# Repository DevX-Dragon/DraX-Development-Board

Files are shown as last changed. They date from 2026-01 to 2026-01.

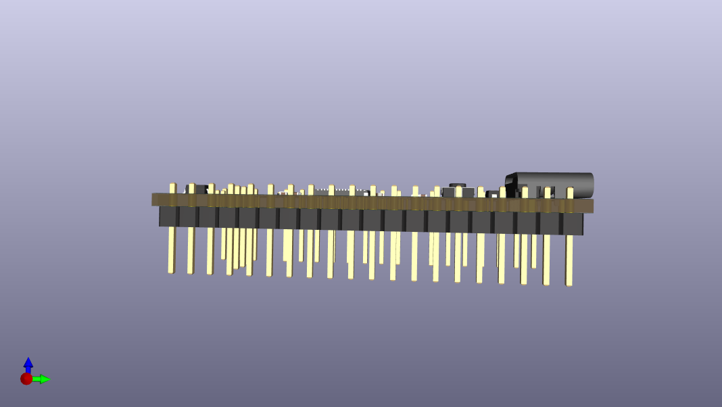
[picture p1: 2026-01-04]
Images/Board 3D side.png

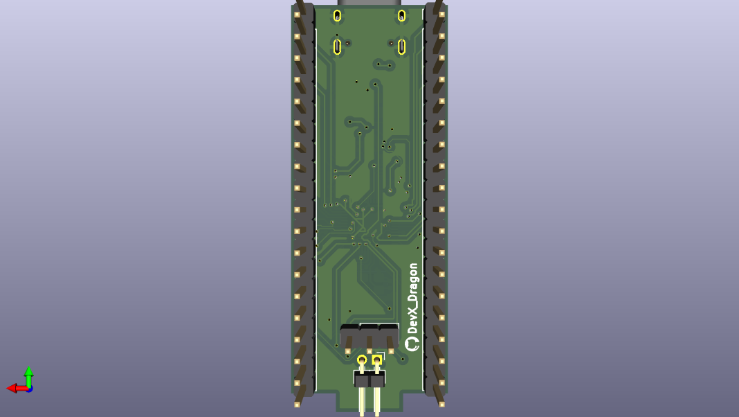
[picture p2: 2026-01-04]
Images/Board 3D back.png

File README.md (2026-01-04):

# DraX Development Board
A compact, high-performance development board based on the RP2040 microcontroller, designed for versatility with dual power options and easy breadboard integration.

## Layouts
PCB Layout

Schematics Layout

## Renders
front view
Front
back
side

## Technical Specifications

**Microcontroller:**
Raspberry Pi RP2040 dual-core ARM Cortex-M0+.

**Storage:** 
16MB (128Mbit) QSPI Flash memory (W25Q128).

**Power Input:** 
Dual-power path with Schottky diode protection (D1, D2).

**USB-C:**
5V via 14-pin USB-C receptacle.

**Battery:**
JST-style connector for LiPo battery support.

**Regulation:**
On-board LDO regulator (NCP1117) providing stable 3.3V.

**Clock:**
12MHz crystal oscillator with 15pF load capacitors.

**I/O:**
40-pin total breakout via dual 20-pin headers (J2, J3) including GPIO and ADC.

**Debugging:**
Dedicated SWD (Serial Wire Debug) header (J4).

**User Interface:**
Tactile Push-buttons for Reset and BOOTSEL modes.

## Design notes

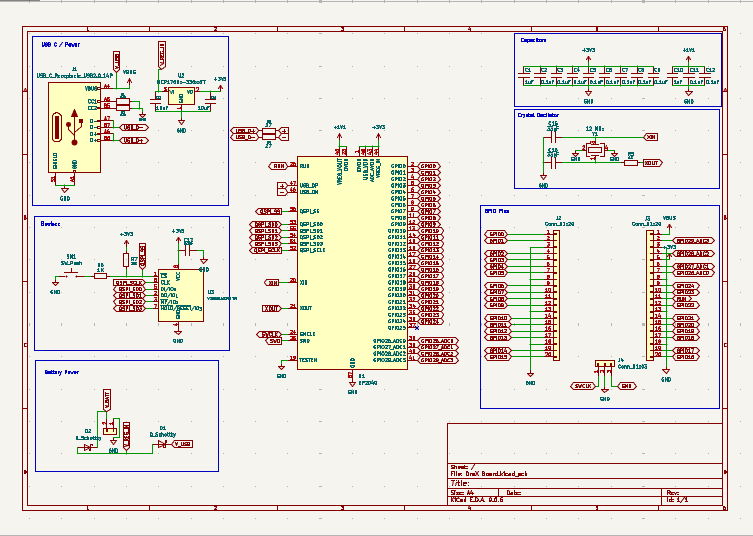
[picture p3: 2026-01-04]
Images/Schematics Layout.png

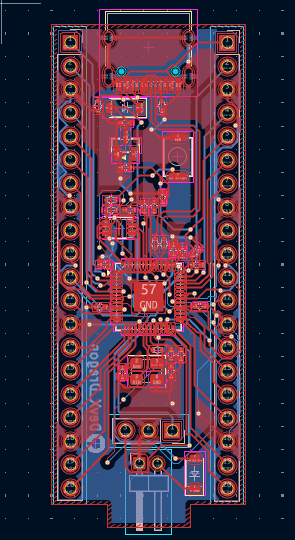
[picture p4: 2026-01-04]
Images/PCB Layout.png

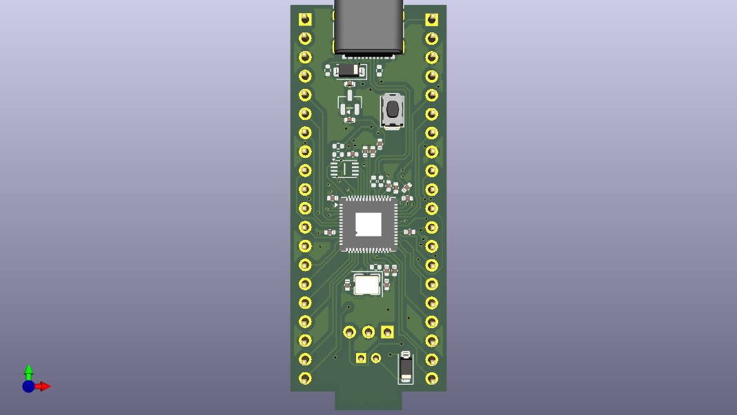
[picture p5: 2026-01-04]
Images/Board 3D front.png

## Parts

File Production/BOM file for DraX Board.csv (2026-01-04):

Designator | Footprint | Quantity | Comment | Supplier and ref
C13, C14 | C_0402_1005Metric | 2 | 10uF
R7, R6 | R_0402_1005Metric | 2 | 10K / 1K
C8, C4, C11, C7, C12, C5, C17, C9, C3, C2, C6 | C_0402_1005Metric | 11 | 0.1uF
R5 | R_0402_1005Metric | 1 | 1K
R1, R2 | R_0402_1005Metric | 2 | 5.1K
R4, R3 | R_0402_1005Metric | 2 | 27
C16, C15 | C_0402_1005Metric | 2 | 33pF
U3 | Winbond_USON-8-1EP_3x2mm_P0.5mm_EP0.2x1.6mm | 1 | W25Q16JVZPIQ TR
J1 | USB_C_Receptacle_HRO_TYPE-C-31-M-12 | 1 | USB_C_Receptacle_USB2.0_14P
C1, C10 | C_0402_1005Metric | 2 | 1uF
U1 | QFN-56-1EP_7x7mm_P0.4mm_EP3.2x3.2mm | 1 | RP2040
D1, D2 | D_SOD-123 | 2 | D_Schottky
Y1 | Crystal_SMD_3225-4Pin_3.2x2.5mm | 1 | 12 MHz
U2 | SOT-23 | 1 | MCP1700x-330xxTT
J3, J2 | PinHeader_1x20_P2.54mm_Vertical | 2 | Conn_01x20
J4 | PinHeader_1x03_P2.54mm_Vertical | 1 | Conn_01x03
J5 | PinHeader_1x02_P2.00mm_Horizontal | 1 | Conn_01x02
SW1 | SW_Push_SPST_NO_Alps_SKRK | 1 | SW_Push

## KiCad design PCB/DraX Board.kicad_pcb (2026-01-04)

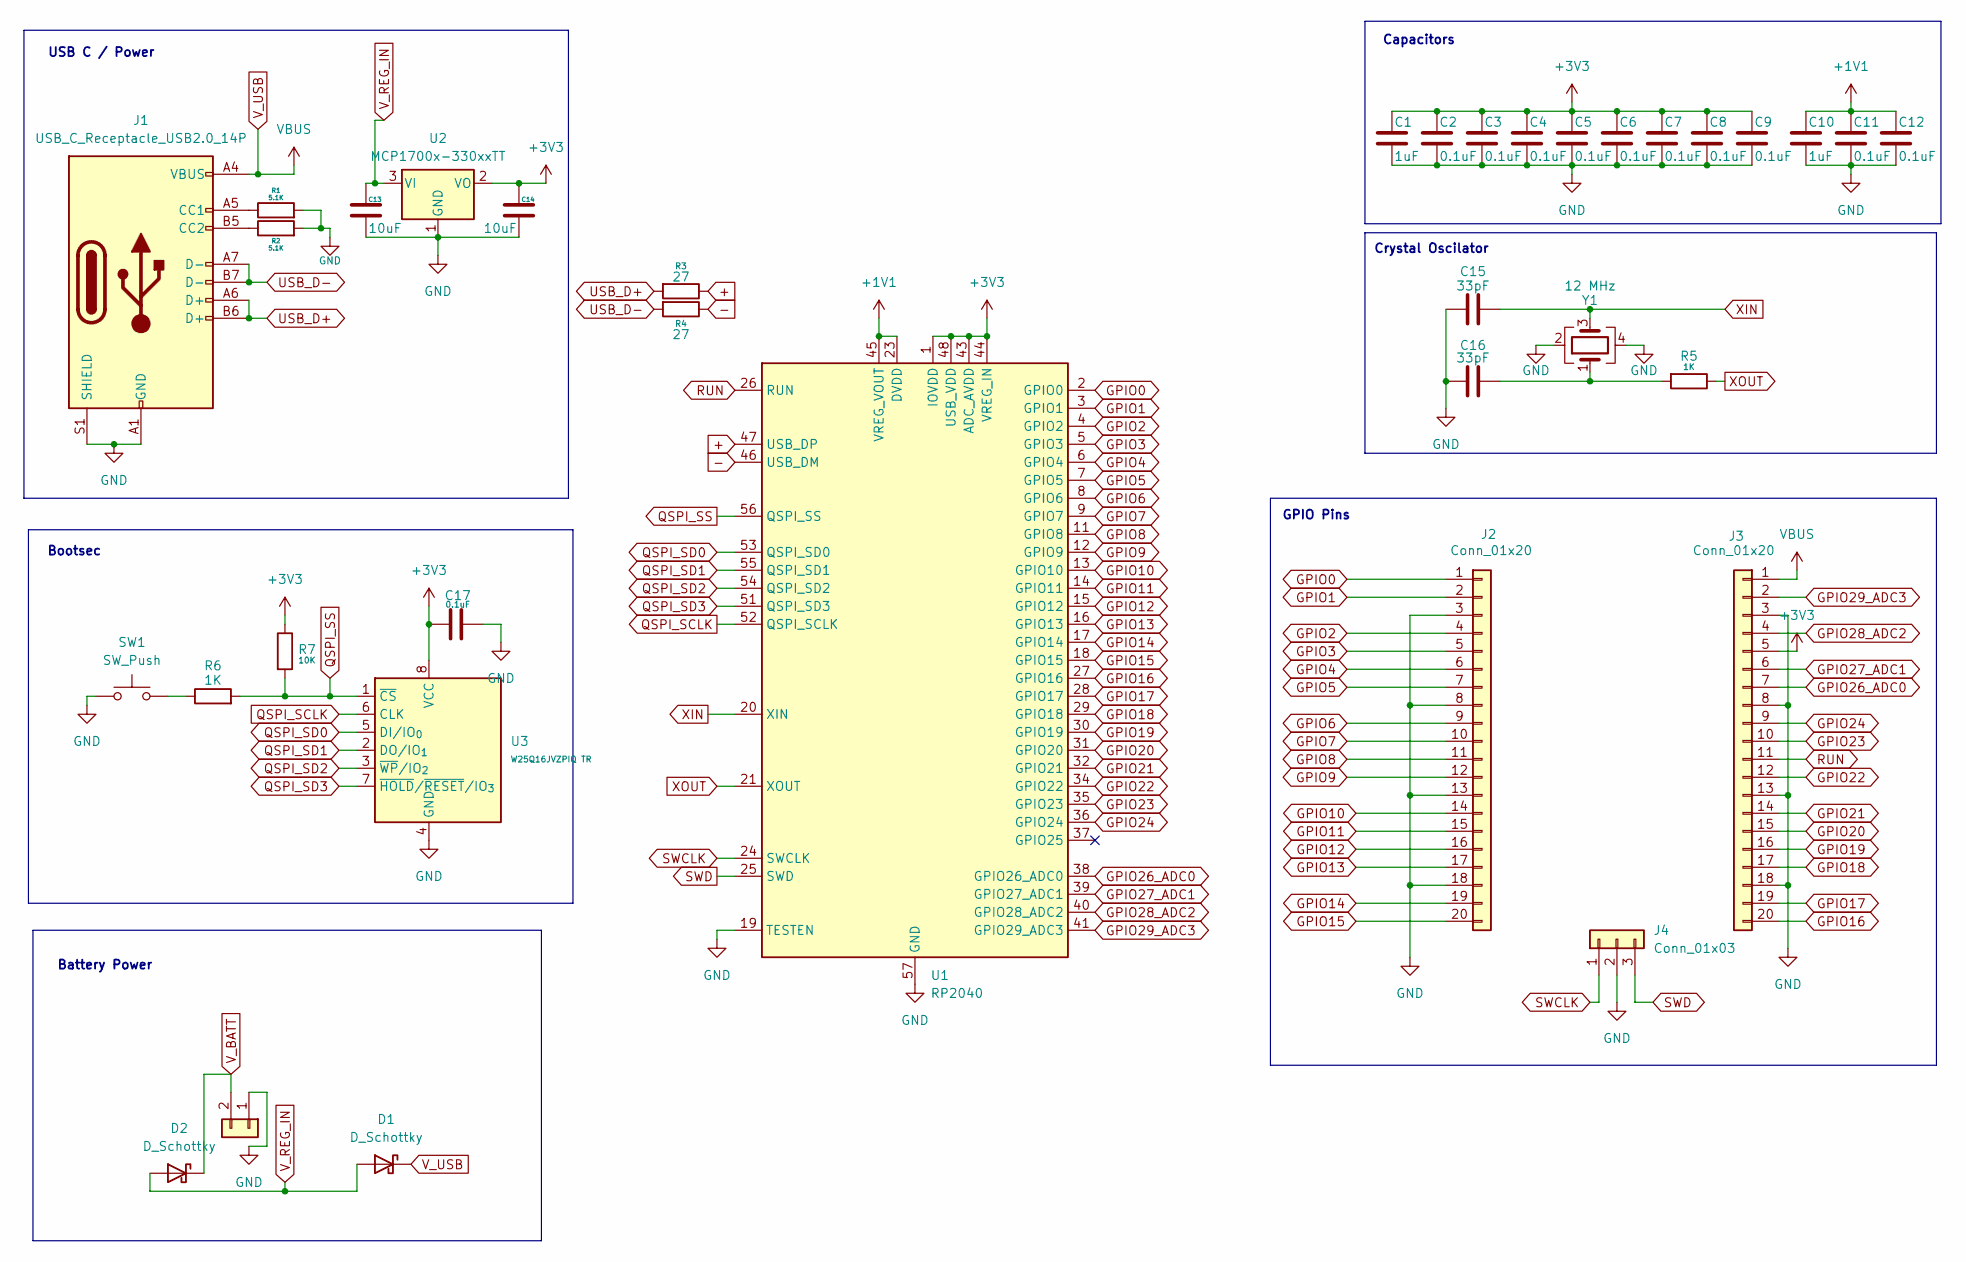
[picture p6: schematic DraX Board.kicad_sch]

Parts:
C1, C10: 1uF; C_0402_1005Metric
C2, C3, C4, C5, C6, C7, C8, C9, C11, C12, C17: 0.1uF; C_0402_1005Metric
C13, C14: 10uF; C_0402_1005Metric
C15, C16: 33pF; C_0402_1005Metric
D1, D2: D_Schottky; D_SOD-123
J1: USB_C_Receptacle_USB2.0_14P; USB_C_Receptacle_HRO_TYPE-C-31-M-12
J2, J3: Conn_01x20; PinHeader_1x20_P2.54mm_Vertical
J4: Conn_01x03; PinHeader_1x03_P2.54mm_Vertical
J5: Conn_01x02; PinHeader_1x02_P2.00mm_Horizontal
R1, R2: 5.1K; R_0402_1005Metric
R3, R4: 27; R_0402_1005Metric
R5, R6: 1K; R_0402_1005Metric
R7: 10K; R_0402_1005Metric
SW1: SW_Push; SW_Push_SPST_NO_Alps_SKRK
U1: RP2040; QFN-56-1EP_7x7mm_P0.4mm_EP3.2x3.2mm
U2: MCP1700x-330xxTT; SOT-23
U3: W25Q16JVZPIQ TR; Winbond_USON-8-1EP_3x2mm_P0.5mm_EP0.2x1.6mm
Y1: 12 MHz; Crystal_SMD_3225-4Pin_3.2x2.5mm

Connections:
+: R3.1, U1.47 (USB_DP)
+1V1: C10.1, C11.1, C12.1, U1.23 (DVDD), U1.45 (VREG_VOUT), U1.50 (DVDD)
+3V3: C1.1, C2.1, C3.1, C4.1, C5.1, C6.1, C7.1, C8.1, C9.1, C14.1, C17.1, J3.5, R7.1, U1.1 (IOVDD), U1.10 (IOVDD), U1.22 (IOVDD), U1.33 (IOVDD), U1.42 (IOVDD), U1.43 (ADC_AVDD), U1.44 (VREG_IN), U1.48 (USB_VDD), U1.49 (IOVDD), U2.2 (VO), U3.8 (VCC)
-: R4.1, U1.46 (USB_DM)
GND: C1.2, C2.2, C3.2, C4.2, C5.2, C6.2, C7.2, C8.2, C9.2, C10.2, C11.2, C12.2, C13.2, C14.2, C15.1, C16.1, C17.2, J1.A1 (GND), J1.A12 (GND), J1.B1 (GND), J1.B12 (GND), J1.S1 (SHIELD), J2.3, J2.8, J2.13, J2.18, J3.3, J3.8, J3.13, J3.18, J4.2, J5.1, R1.2, R2.2, SW1.1, U1.19 (TESTEN), U1.57 (GND), U2.1 (GND), U3.4 (GND), Y1.2, Y1.4
GPIO0: J2.1, U1.2 (GPIO0)
GPIO1: J2.2, U1.3 (GPIO1)
GPIO2: J2.4, U1.4 (GPIO2)
GPIO3: J2.5, U1.5 (GPIO3)
GPIO4: J2.6, U1.6 (GPIO4)
GPIO5: J2.7, U1.7 (GPIO5)
GPIO6: J2.9, U1.8 (GPIO6)
GPIO7: J2.10, U1.9 (GPIO7)
GPIO8: J2.11, U1.11 (GPIO8)
GPIO9: J2.12, U1.12 (GPIO9)
GPIO10: J2.14, U1.13 (GPIO10)
GPIO11: J2.15, U1.14 (GPIO11)
GPIO12: J2.16, U1.15 (GPIO12)
GPIO13: J2.17, U1.16 (GPIO13)
GPIO14: J2.19, U1.17 (GPIO14)
GPIO15: J2.20, U1.18 (GPIO15)
GPIO16: J3.20, U1.27 (GPIO16)
GPIO17: J3.19, U1.28 (GPIO17)
GPIO18: J3.17, U1.29 (GPIO18)
GPIO19: J3.16, U1.30 (GPIO19)
GPIO20: J3.15, U1.31 (GPIO20)
GPIO21: J3.14, U1.32 (GPIO21)
GPIO22: J3.12, U1.34 (GPIO22)
GPIO23: J3.10, U1.35 (GPIO23)
GPIO24: J3.9, U1.36 (GPIO24)
GPIO26_ADC0: J3.7, U1.38 (GPIO26_ADC0)
GPIO27_ADC1: J3.6, U1.39 (GPIO27_ADC1)
GPIO28_ADC2: J3.4, U1.40 (GPIO28_ADC2)
GPIO29_ADC3: J3.2, U1.41 (GPIO29_ADC3)
unnamed: C16.2, R5.2, Y1.1
unnamed: J1.A5 (CC1), R1.1
unnamed: J1.B5 (CC2), R2.1
unnamed: R6.1, SW1.2
QSPI_SCLK: U1.52 (QSPI_SCLK), U3.6 (CLK)
QSPI_SD0: U1.53 (QSPI_SD0), U3.5 (DI/IO_{0})
QSPI_SD1: U1.55 (QSPI_SD1), U3.2 (DO/IO_{1})
QSPI_SD2: U1.54 (QSPI_SD2), U3.3 (~WP/IO_{2})
QSPI_SD3: U1.51 (QSPI_SD3), U3.7 (~HOLD/~RESET/IO_{3})
QSPI_SS: R6.2, R7.2, U1.56 (QSPI_SS), U3.1 (~CS)
RUN: J3.11, U1.26 (RUN)
SWCLK: J4.1, U1.24 (SWCLK)
SWD: J4.3, U1.25 (SWD)
USB_D+: J1.A6 (D+), J1.B6 (D+), R3.2
USB_D-: J1.A7 (D-), J1.B7 (D-), R4.2
V_BATT: D2.1 (K), J5.2
V_REG_IN: C13.1, D1.2 (A), D2.2 (A), U2.3 (VI)
V_USB: D1.1 (K), J1.A4 (VBUS), J1.A9 (VBUS), J1.B4 (VBUS), J1.B9 (VBUS), J3.1
XIN: C15.2, U1.20 (XIN), Y1.3
XOUT: R5.1, U1.21 (XOUT)

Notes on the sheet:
GPIO Pins
USB C / Power
Crystal Oscilator
Capacitors
Bootsec
Battery Power

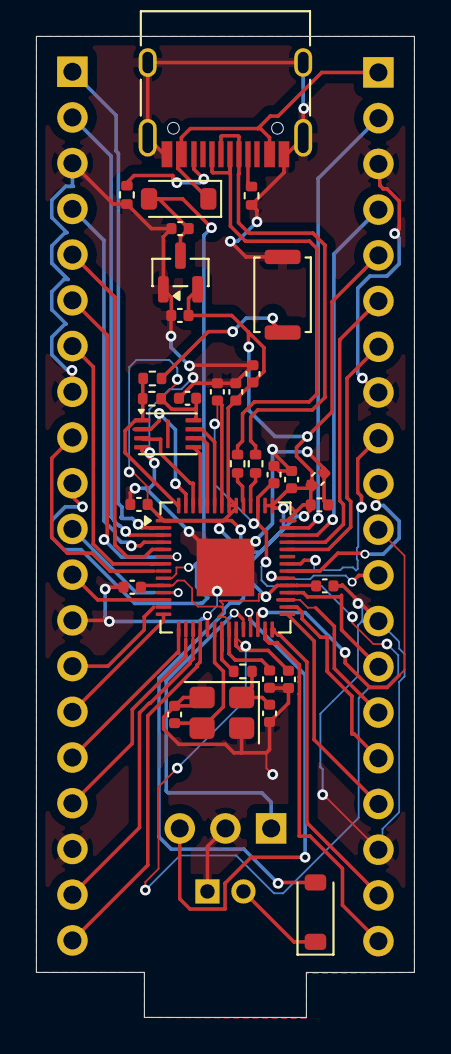
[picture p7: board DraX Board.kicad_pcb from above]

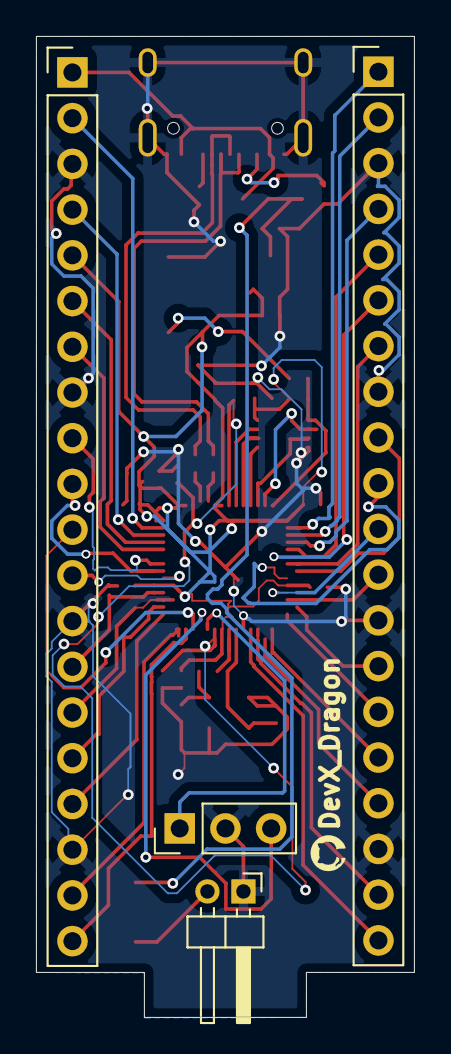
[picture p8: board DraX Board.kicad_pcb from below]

Board: 2 copper layers, 21.0 x 54.5 mm, 36 parts (4 on the bottom side), 54 nets.
